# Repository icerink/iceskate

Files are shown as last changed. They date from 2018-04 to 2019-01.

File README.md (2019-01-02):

# iceskate
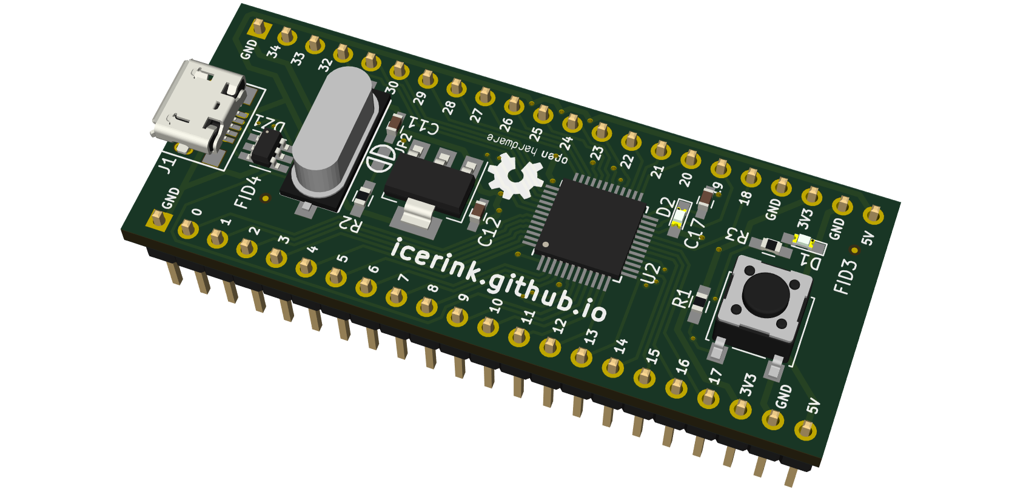
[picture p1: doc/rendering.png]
rendering of the board


A low cost FPGA development board for absolute newbies.

## Why?
Getting started with FPGA design is hard. Unnecessarily hard.

## How?
Everyone knows how to use a browser. Many people know (some) webdesign.

The [*icerink*](https://github.com/icerink) ecosystem tries to exploit this by building a complete browser centric FPGA workflow. Edit, synthesize and upload FPGA designs from within your browser.

Doing this lowers the boarding hurdle by not requiring the installation of toolchains. Just plug in the board and begin to play :).

## What?
Mainly a FPGA and a USB interface. Not much more. 

The main source of inspiration for this board was the [upduino](http://gnarlygrey.atspace.cc/development-platform.html) by Gnarly Grey. We tried to build a similarly minimal and cheap board. The main Hardware feature, our board employs additionally, is the Microcontroller that is capable of speaking a wide variety of USB-Protocols.

In the *icerink* ecosystem, this capability is used to access the FPGA board from within the browser. 

The iceskate board features:
* The [ICE40UP5K](http://datasheet.octopart.com/ICE40UP5K-SG48ITR50-Lattice-Semiconductor-datasheet-101745901.pdf) FPGA (with experimential support in project icestorm, an open source fpga toolchain)
* An [STM32F070F6P6](http://datasheet.octopart.com/STM32F070F6P6-STMicroelectronics-datasheet-36993117.pdf)
* A single user definable push button and
* A user definable LED

## How to get one?
Build one yourself!

The board is optimized for hand soldering and has a [BOM cost](https://octopart.com/bom-tool/w8mU938s) of ~10€ when you build 10. The PCB can be ordered online at most common PCB manufacturers. We Ordered our boards at jlcpcb. 
[Assembly instructiost can be found here.](https://icerink.github.io/iceskate/)

## Can I help?
Definitely.

If you want to contribute to the hardware design or help with any other thing, do not hesitate to use the issue tracker to get in touch :).

However, it would be nice if you talk to us, **before** you start writing code and invest your time ;).

To develop the board, clone this repository with 
`git clone --recursive https://github.com/icerink/iceskate`.
Then you can simply use Kicad to edit the scematics and PCB.

```diff
- Warning!
- This Project uses submodules! when you clone without --recursive Kicad wont find some libraries!
```

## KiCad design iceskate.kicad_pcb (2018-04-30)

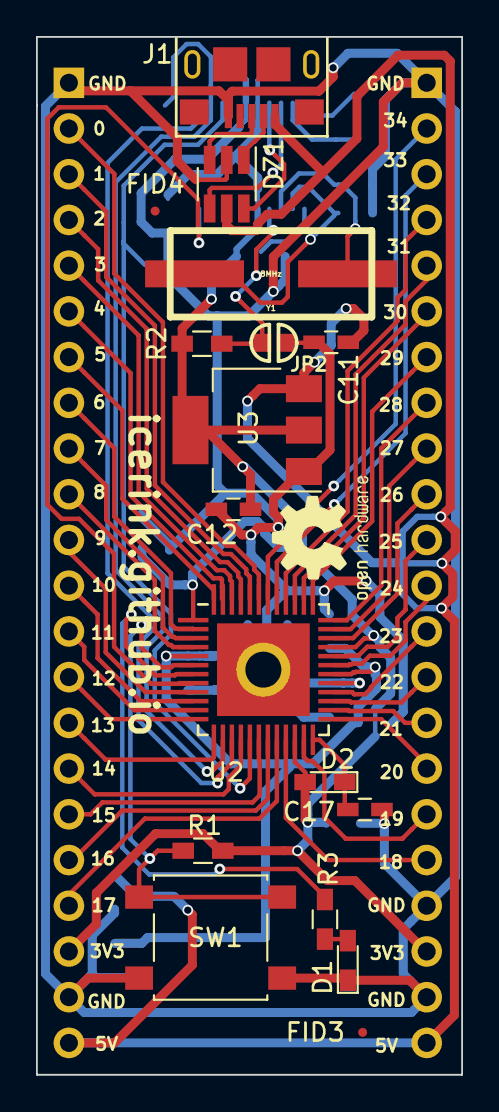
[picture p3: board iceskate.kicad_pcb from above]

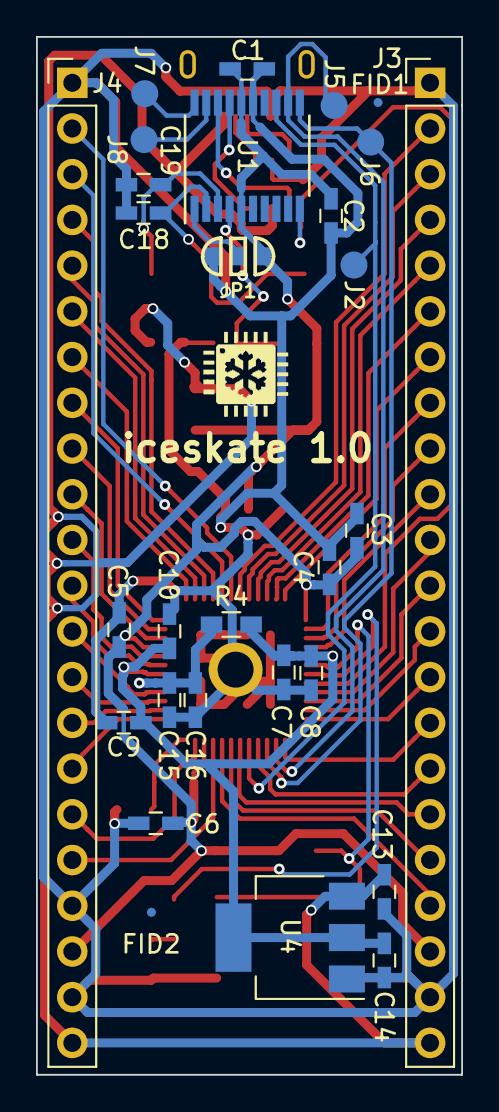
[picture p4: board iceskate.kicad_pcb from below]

Board: 2 copper layers, 23.6 x 57.7 mm, 47 parts (30 on the bottom side), 58 nets.

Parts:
C1, C2: C; C_0603_HandSoldering
C3, C6, C7, C10, C11, C12, C13, C14, C16, C17: 1µ; C_0603_HandSoldering
C4, C5, C8, C9, C15: 0.1µ; C_0603_HandSoldering
C18, C19: 22p; C_0603_HandSoldering
D1: LED; LED_0603_HandSoldering
D2: D; LED_0603_HandSoldering
DZ1: USBLC6-2SC6; SOT-23-6_Handsoldering
FID1, FID2, FID3, FID4: FIDUCIAL; Fiducial_0.5mm_Dia_1mm_Outer
J1: USB_OTG; FCI_10118193-0001LF
J2, J5, J6, J7, J8: TEST_1P; Measurement_Point_Round-SMD-Pad_Small
J3, J4: Conn_01x22; Pin_Header_Straight_1x22_Pitch2.54mm
JP1: Jumper_NC_Dual; SOLDER-JUMPER_2-WAY
JP2: Jumper; SOLDER-JUMPER_1-WAY
LOGO: logo
R1, R2: 10k; R_0603_HandSoldering
R3: 100; R_0603_HandSoldering
R4: 10; R_0603_HandSoldering
SW1: SW_Push; SW_SPST_B3S-1000
U1: STM32F070F6P6; TSSOP-20_4.4x6.5mm_Pitch0.65mm
U2: ICE40UP5K-SG48; QFN-48-1EP_7x7mm_Pitch0.5mm
U3: LD1117S33TR_SOT223; SOT-223-3_TabPin2
U4: LD1117S12TR_SOT223; SOT-223-3_TabPin2
Y1: 8MHz; HC49%2fUS

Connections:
+1V2: C7.1, C8.1, C9.1, C10.1, C14.1, R4.1, U2.5, U2.30, U4.2
+2V5: C17.1, D2.1, U2.24
+3V3: C1.1, C2.1, C3.1, C4.1, C5.1, C6.1, C12.1, D2.2, J3.20, J4.20, JP1.3, R1.1, R2.2, U1.5, U1.16, U2.1, U2.22, U2.33, U3.2
+5V: C11.1, C13.1, DZ1.5, J1.1, J3.22, J4.22, U3.3, U4.3
/IO_0: J3.2, U2.43
/IO_1: J3.3, U2.44
/IO_2: J3.4, U2.45
/IO_3: J3.5, U2.46
/IO_4: J3.6, U2.47
/IO_5: J3.7, U2.48
/IO_6: J3.8, U2.2
/IO_7: J3.9, U2.3
/IO_8: J3.10, U2.4
/IO_9: J3.11, U2.9
/IO_10: J3.12, U2.10
/IO_11: J3.13, U2.11
/IO_12: J3.14, U2.12
/IO_13: J3.15, U2.13
/IO_14: J3.16, U2.16
/IO_15: J3.17, U2.18
/IO_16: J3.18, U2.19
/IO_17: J3.19, U2.20
/IO_18: J4.18, U2.21
/IO_19: J4.17, U2.23
/IO_20: J4.16, U2.25
/IO_21: J4.15, U2.26
/IO_22: J4.14, U2.27
/IO_23: J4.13, U2.28
/IO_24: J4.12, U2.31
/IO_25: J4.11, U2.32
/IO_26: J4.10, U2.34
/IO_27: J4.9, U2.35
/IO_28: J4.8, U2.36
/IO_29: J4.7, U2.37
/IO_30: J4.6, U2.38
/IO_31: J4.5, U2.39
/IO_32: J4.4, U2.40
/IO_33: J4.3, U2.41
/IO_34: J4.2, U2.42
/IO_BTN: R1.2, SW1.1, U2.6
/IO_LED: R3.2, U2.7
/RESET: U1.10, U2.8
/SPI_MISO: J5.1, U1.12, U2.14
/SPI_MOSI: J2.1, U1.13, U2.17
/SPI_SCK: J6.1, U1.11, U2.15
/USB_D+: DZ1.4, U1.18
/USB_D-: DZ1.6, U1.17
GND: C1.2, C2.2, C3.2, C4.2, C5.2, C6.2, C7.2, C8.2, C9.2, C10.2, C11.2, C12.2, C13.2, C14.2, C15.2, C16.2, C17.2, C18.1, C19.2, D1.1, DZ1.2, J1.5, J3.1, J3.21, J4.1, J4.19, J4.21, JP1.1, JP2.1, SW1.2, U1.15, U2.49, U3.1, U4.1
unnamed: C15.1, C16.1, R4.2, U2.29
unnamed: C18.2, U1.2, Y1.2
unnamed: C19.1, U1.3, Y1.1
unnamed: D1.2, R3.1
unnamed: DZ1.1, J1.2
unnamed: DZ1.3, J1.3
unnamed: J7.1, U1.20
unnamed: J8.1, U1.19
unnamed: JP1.2, U1.1
unnamed: JP2.2, R2.1, U1.4

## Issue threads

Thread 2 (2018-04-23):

add crystal oscillator

anuejn, 2018-04-23:
Idk, wether the stm32 really needs this to be able to to usb...

Closed 2018-04-24.

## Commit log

2018-04-21 initial schematic
    [iceglue.sch]
2018-04-21 begin placing
    [iceglue.kicad_pcb, iceglue.sch]
2018-04-22 fully layouted; ready to use ;)
    [iceglue.kicad_pcb, iceglue.sch]
2018-04-22 minor corrections
    [iceglue.kicad_pcb]
2018-04-23 add logo
    [iceglue.sch]
2018-04-23 add remaining 3d models; closes #3
    [iceglue.kicad_pcb]
2018-04-23 add crystal and usb esd; crystal has to be somwhere else
    [iceglue.kicad_pcb, iceglue.sch]
2018-04-23 move crystal to be not _that_ bad
    [iceglue.kicad_pcb]
2018-04-24 add silkscreen layout + logos; closes #1
    [iceglue.kicad_pcb, iceglue.sch]
2018-04-30 add io labels; optimize silkscreen
    [iceglue.kicad_pcb]
2018-04-30 rename project files
    [iceskate.kicad_pcb, iceskate.sch]
2019-01-02 add link to assembly instructions
